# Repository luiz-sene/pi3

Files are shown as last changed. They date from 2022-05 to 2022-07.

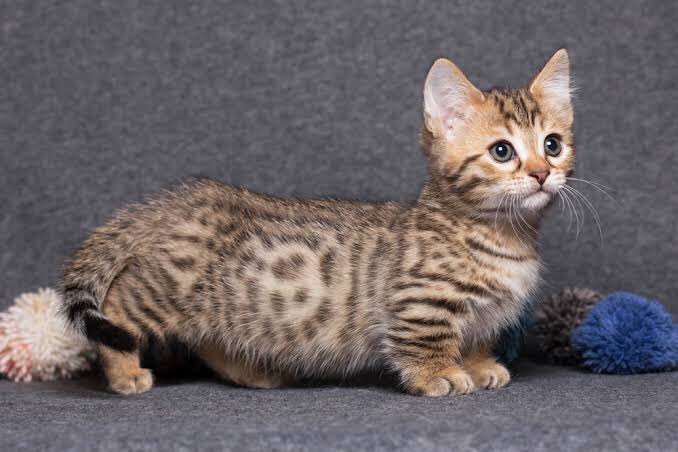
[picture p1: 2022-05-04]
Imagens/image.png

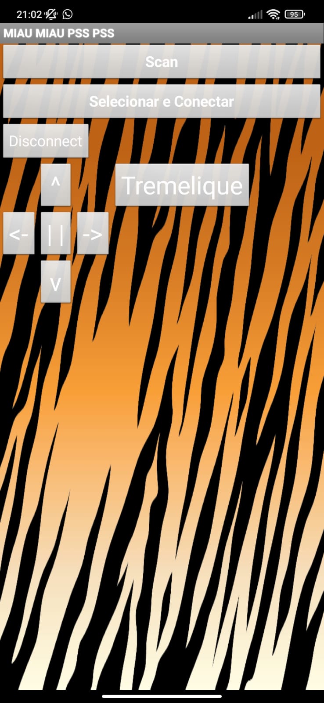
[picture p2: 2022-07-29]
Imagens/App Miau Miau.jpeg

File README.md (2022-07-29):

 # README

Este repositório possui o desenvolvimento do projeto da disciplina Projeto Integrador III realizado pelo alunos Julio Sidney Veras Pacheco e Luiz Fernando Assis Sene.

[Concepção](https://github.com/juliopacheco12/PIN22107/blob/main/CONCEPÇÃO.md)

[Design](https://github.com/juliopacheco12/PIN22107/blob/main/Design.md)

[Implementação](https://github.com/juliopacheco12/PIN22107/blob/main/Implementação.md)

[Repositório de Códigos de Programação](https://github.com/juliopacheco12/PIN22107/tree/main/Programação)

[Repositório de Projeto de PCI](https://github.com/juliopacheco12/PIN22107/tree/main/PCI)

[Repositório do App](https://github.com/juliopacheco12/PIN22107/tree/main/App)

[Repositório de Imagens](https://github.com/juliopacheco12/PIN22107/tree/main/Imagens)

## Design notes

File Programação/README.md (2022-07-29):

# Repositorio de codigos e configurações

Todos os codigos foram gerados tendo como alvo o microcontrolador ESP32. Os arquivos principais se encontram na pasta Main e estão divididos da seguinte forma:

Main - arquivo principal.

servomotor.c/.h - inicialização do motor, configuração dos parametros necessários e a função para ele seja ativado.

sensor.c/.h     - inicialização do sensor, configuração dos parametros necessários e uma função para detectar o obstaculo e ativar o motor.

pwm.c/.h        - inicialização dos pwm, configuração dos parametros necessários e funções para definir a movimentação do carrinho

bt.c/.h         - repositorio de codigos relacionados ao bluetooth. E nele tambem onde a informação enviada pelo aplicativo e recebida e então ele chama a função
                  desejada pelo usuario, como se movimentar ou ativar o motor. Na linha 377 do bt.c e possível ver quando o evento de escrita e ativado e como é
                  feita a comparação para que a função correta seja chamada.

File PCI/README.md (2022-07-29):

#PCI
Pasta com arquivos do projeto da PCI utilizada para acoplar o ESP32 ao carrinho do IFSC

## PINAGEM
|Signal|ESP Pin|
|:-:|:-:|
|Echo 0|32|
|Triger 0|33|
|Echo 1|23|
|Triger 1|22|
|Optico Direita|2|
|Optico Esquerda|15|
|PWM 1|19|
|PWM 1N|18|
|PWM 2|26|
|PWM 2N|25|
|Servo Motor|4|
|Sensor de presença|12|

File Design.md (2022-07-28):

# Design
Seguindo as necessidades apontadas na concepção do projeto, apresentaremos os componentes que serão utilizados neste projeto, bem como analisaremos as escolhas de acordo com as caracteristicas de alguns componentes do mercado.

## Componentes

|Quantidade|Componente|Custo no Mercado|Custo no Projeto|
|:-:|:-:|:-:|:-:|
|1|Microcontrolador|R$69,90|R$-|
|1|Módulo Bluetooth|Integrado ao Microcontrolador|R$-|
|1|Sensor de Obstáculo|R$49,90|R$-|
|1|Servomotor|R$59,90||
|1|Bateria 9V recarregavel|R$19,98|R$-|
|1|Haste Flexivel com bagulhinho na ponta|R$-|R$-|
|1|Módulo de carrinho Vrum Vrum|R$-|R$-|
||Total|R$199,98|R$0,00|

O custo total deste projeto foi zerado pois todos os componentes utilizados estavam disponíveis nos laboratórios do DAELN/IFSC.

## Bluetooth VS WiFi

|#|  **BLUETOOTH** | **WIFI** |
|:-|:-:|:-:|
|Protocolo de Comunicação|IEEE 802.15.1|802.11|
|Frequencia (Hz)|2,4G|2,4~5G|
|Alcance|Até 100m|Maior que 100m|
|Custo de Mercado*|R$27,90|R$24,90|
|Alimentação|Baixo Consumo|Alto Consumo|
|Vantagem|Baixo Custo|Longo Alcance|
|Desvantagem|Baixo Alcance|Alto consumo energético|

*Pesquisado em 04/05/2022 - FilipeFlop

### Escolha
O módulo de comunicação escolhido foi o bluetooth devido ao baixo consumo energético deste dispositivo; apesar do baixo alcançe, atende a necessidade deste projeto; além disso, já temos familiardade com este dispositivo devido a trabalhos anteriores.

## Microcontrolador

Possibilidades
 1. ESP32
 2. Cortex M3
 3. ATMEGA328

O microcontrolador escolhido foi o ESP32, pois é o que melhor atende as nossas necessidades. Ele já possui módulos de comunicação bluetooth e wifi integrados, possui 4Mb de memória flash, que será utilizada para armazenamento dos dados coletados da aplicação, é um componnente que possui uma boa eficiencia no consumo energético, com diversos modos sleeps. Ele possui uma quantidade de pinos suficiente para este projeto, com 18 canais ADC, 34 portas GPIO, PWM e outras.

Além disso, ele está disponível junto ao professor Charles, que trabalhará com este microcontrolador na disciplina de Microcontroladores 2.

## Framework

Foi utilizado o framework ESP-IDF, que é o framework oficial da Espressif para o desenvolvimento de aplicações parar toda a família ESP32.

## ServoMotor

Já tivemos experiência com o Servomotor Tower Pro SG90. Este servomotor pode rotacionar em aproximadamente 180º, 90º para cada lado. Possui cerca de 9g e 3 pinos analógicos: VCC, GND e comando. Ele opera em um torque de 8kgfcm, velocidade de 60º/0.1s e tensão de operação de 3V a 7,2V. Por fim, ele é um dos mais baratos do mercado. Infelizmente, este componente é extremamente frágil e não conseguiremos utilizá-lo de forma satisfatória. 

Outro servomotor disponível nos laboratórios foi o MG995. O Servo TowerPro MG995 possui ótima qualidade e alto torque, todas as suas engrenagens são metálicas, possui faixa de rotação de 180 graus, a tensão de operação é de 4,8V a 7,2V (facilmente atingida por meio das baterias do carrinho). Por fim, sua escolha se deu principalmente por sua robustez, que atingia as necessidades do projeto.

## Sensor de proximidade

O sensor de obstáculo é um circuito composto por um emissor e um receptor IR, mais o CI comparador LM393, que facilita sua conexão com Arduino, PIC ou Raspberry Pi, visto que sua tensão é de 3,3-5V.

Seu funcionamento é simples: quando algum obstáculo é colocado em frente ao sensor, o sinal infravermelho é refletido para o receptor. Quando isso acontece, o pino de saída OUT é colocado em nível baixo (0), e o led verde do módulo é aceso, indicando que algum obstáculo foi detectado.

O alcance do sensor é de 3 à 80 cm, que pode ser ajustado por meio do potenciômetro na placa. O sensor de obstáculo é um componente que atende as nossas necessidades.

### Escolha

Sensor de Obstaculo Infravermelho - E18-D80NK

## Bateria

2 Baterias de litio em série que já estão inseridas no prototipo do carrinho disponibilizado pelo DAELN 3,7V. Para alimentar o esp32 foi utilizado um Power Bank independente de 5V.

## Regulador de tensão chaveado

Regulador de Tensão LM2596 Conversor DC-DC Step Down ou similar

## Interface para Usuário

Existem alguns softwares no mercado para implementar uma interface de controle para o usuário. Neste projeto, pensamos em 2 opções: implementar uma interface para o usuário no Qt Creator, orientando toda a programação deste projeto a objetos; ou utilizar o MIT App Inventor para implementar um aplicativo para smartphone.

O Qt Creator é um ambiente de desenvolvimento integrado (IDE) multiplataforma criado para a máxima experiência do desenvolvedor. O Qt Creator é executado nos sistemas operacionais de desktop Windows, Linux e macOS e permite que os desenvolvedores criem software em plataformas desktop, móveis e incorporadas.

O MIT App Inventor é um ambiente de programação visual intuitivo que permite que todos criem aplicativos totalmente funcionais para telefones Android, iPhones e tablets Android/iOS. Essa ferramenta é baseada em blocos, facilitando a criação de aplicativos complexos e de alto impacto em um tempo significativamente menor do que os ambientes de programação tradicionais.

No caso do Qt Creator, pudemos ter o auxilio e orientação do Profº Hugo Marcondes, na disciplina de Programação Orientada a Objetos. No entanto, nesta disciplina utilizamos apenas o framework do Arduino para implementar nossos objetivos. Como este framework era dispensável para a disciplina de Projeto Integrador III, implementamos também uma interface final no MIT App Inventor.

## Placa de Circuito Impresso

Foi implementado também uma placa de circuito impresso para acoplar com facilidade o microcontrolador escolhido com o cabo flet do carrinho. Para isto, foi utilizado o software KiCad, que é um programa computacional de código aberto para projeto eletrônico assistido por computador, com o objetivo de facilitar a concepção de layouts e suas conversões para placas de circuito impresso. Além dele, foi utilizado as instalações do IFSC para a confecção da placa.

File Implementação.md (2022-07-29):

# IMPLEMENTAÇÃO
Nesta etapa do projeto colocaremos em prática o que foi abordado e definido pelas etapas anteriores. De forma a atingir os objetivos estipulados, podemos definir duas diferentes frentes de trabalho. Programação e Montagem do equipamento.

## Programação

O primeiro passo foi realizar testes com os componentes individualmente de forma a verificar e compreender seu funcionamento. Ao longo deste processo pode-se notar que muito do que era feito ali poderia e foi integrado ao código final. Para tal, foi instalado o ESP-IDF, o qual foi utilizado junto ao VS-CODE para implementar todas as funcionalidades desejadas. Este ambiente de desenvolvimento suporta as linguagens C e C++, além de já possuir alguns exemplos que nos guiaram. Apesar destes exemplos, é importante destacar a grande dificuldade de encontrar bibliografia suficiente para o entendimento pleno da utilização deste framework.

Cada componente foi testado separadamente através de rotinas simples, após isso métodos de interação entre eles foram gerados, resultando em um código funcional que atende as exigências do projeto. Inicialmente, optamos por realizar a comunicação via bluetooth, visto que a partir deste ponto poderíamos prosseguir com a implementação de todo o restante das nossas funcionalidades de forma mais fluída. Para os futuros projetos que desejem seguir com esta implementação, é importante mencionar que foi justamente aqui que encontramos a nossa maior dificuldade durante todo o processo: tornar o código exemplo do Bluetooth em modo de economia de energia funcional às nossas necessidades. Após muito estudo, conseguimos manipular os dados enviados ao esp32 de forma que para cada dado recebido uma ação fosse desencadeada, uma mensagem serial de confirmação também é exibida no serial monitor. Embora para este projeto não tenha sido utilizado, o ato do esp32 enviar dados via bluetooth e não apenas receber, também está funcional. Após a comunicação ser implementada conforme desejávamos, iniciamos a criação do Aplicativo para Smartphone, a qual seria a nossa interface de controle do usuário. O objetivo desta interface era escanear a procura do dispositvo bluetooth desejado, esp32, e uma vez conectado que ele pudesse enviar dados de forma que controlasse o movimento do carrinho e o motor da haste. Para que esta comunicação fosse realizada ambos os dispositvos, a interface e o esp32, precisavam ter o mesmo service uuid, um numero de 128 bits utilizado para identificar informações, uma vez que ele não era disponibilizado na documentação do ESP-IDF foi utilizado um aplicativo disponivel na playstore para se conectar com o microcontrolador e uma vez que ele enviava dados era possivel analisar o log gerado por esse aplicativo para identificar esse numero e implementa-lo na interface. Para o caso dos motores do carrinho, foi importante entender a documentação disposta no GitHub do LPAE, encontrada [clicando neste link](https://github.com/xtarke/automated_buggy). Implementamos os 4 PWMs necessários para o correto funcinonamento dos motores de acordo com as nossas necessidades. Ao receber os comandos via comunicação bluetooth, o acionamento ocorria de forma satisfatória. Lembrando que o acionamento do carrinho era desejado APENAS por meio da interface do usuário. Por fim, implementamos o servo motor e o sensor de obstáculo. Para o servo motor, implementamos uma rotação de 90º para ambos os lados, fazendo com que este gire o que chamamos de "tremelique". Neste protótipo, implementamos apenas uma volta de 90º no sentido horário e outro no sentido anti-horário, de forma a ser uma validação de conceito. O sensor de obstáculo foi implementado enviando um sinal ao ESP32, o qual ativa o servo motor sempre que o sensor detecta um obstáculo próximo. Portanto, conforme desejado inicialmente, o acionamento do tremelique ocorre por 2 métodos: Controle do usuário por meio do aplicativo, ou aproximação do felino sendo detectada pelo sensor de obstáculo. Após todos os testes individuais, pudemos realizar o código final com todas as aplicações requeridas por este projeto juntas e funcionais. O código podeser acessado por meio do link abaixo. Reforço que ara este código ser compilado, é necessário o a correta instalação do ESP-IDF, bem como a criação de novo projeto.

Aplicativo

### Código esp32
[Clique aqui para ver o código deste projeto](https://github.com/juliopacheco12/PIN22107/tree/main/Programação).

### App
[Clique aqui para ver o código do App](https://github.com/juliopacheco12/PIN22107/tree/main/App)

## Montagem
Assim como na parta da programação, inicialmente realizamos todos os testes individuais, de forma a entender o funcionamento dos componentes utilizados. Caso este projeto seja continuado, é de extrema importância o entendimento do funcionamento do carrinho por meio da documentação disponibilizada pelos laboratórios responsáveis por todos os carrinhos disponibilizados pelo IFSC. O teste dos PWMs ocorreram primeiramente com o auxilio de um osciloscópio, onde pudemos verificar o correto funcionamento. Testamos também este acionamento com o auxilio de 4 leds, onde pudemos verificar o correto acionamento de todas as direções desejadas e acionadas pelo controle do usuário.

Antes de conectar todos os componentes ao carrinho, decidimos testar o acionamento do servo motor e do sensor de obstáculo juntamente aos leds na brotoboard, verificando e corrigindo algumas inconsistências do código. Logo após todos os testes, acoplamos todos os componentes ao carrinho. Nesta etapa, realizamos a calibragem dos PWMs, conseguindo acionar corretamente o giro de todas as rodas, de forma a fazê-lo andar em todas as direções conforme desejado e acionado pelo controle do usuário.

Após confirmarmos o funcionamento de todos os componentes integrados, desejamos corrigir um detalhe que poderia nos causar problemas: a utilização de cabos. Para isto, realizamos a confecção de uma placa de circuito impresso, onde pudemos acoplar o ESP32 de forma a realizar todas as conexões com a mínima utilização de cabos jumper necessária. Acoplamos também o conector para o cabo flat do carrinho, o qual se conectá a todas as funcionalidades que o carrinho possui. Infelizmente, passamos por problemas nesta etapa que nos fez abortar a utilização desta PCI na apresentação final do projeto. Os problemas já foram corrigidos no layout da placa projetada, o qual pode ser encontrado [clicando neste link](https://github.com/juliopacheco12/PIN22107/tree/main/PCI), porém não houve tempo hábil para a nova impressão.

Felizmente, apesar de não ter a placa para acoplar os componentes, realizamos a montagem de todos os componentes "a bordo" do carrinho, e o funcionamento de toda a estrutura pode ser confirmado em sala de aula.

Carrinho

Por fim, devido ao encurtamento do semestre 2022/1, o qual teve menos semanas que um semestre comum no IFSC, visto a necessidade de tornar o calendário acadêmico normal novamente pós pandemia, alguns pontos desejados não puderam ser implementados.
1. Nova placa de circuito impresso;
2. Impressão 3D da haste flexível;
3. Impressão 3D de estrutura de suporte para os componetes para acoplar ao carrinho.

Era de desejo nosso realizar estes três pontos, mas infelizmente não foi possível. Como citado, solucionamos a falta destes pontos da seguinte forma:
1. Estrutura de cabos jumper para conexão entre componentes, validando o caso;
2. Apenas realizando validação do funcionamento servo motor, visto que esta estrutura seria acoplada às hastes giratórias do servo e serviria apenas para "embelezar" o projeto;
3. Acoplar componentes diretamente na estrutura pré existente do carrinho.

## Sugestões para trabalhos futuros
No caso de seguimento deste projeto por algum colega, segue algumas sugestões que podem ser realizadas para aprimorar o projeto:
1. Sanar pontos não implementados citados no tópico anterior;
2. Armazenar dados de utilização;
3. Expor ao usuário dados de utilização do brinquedo;

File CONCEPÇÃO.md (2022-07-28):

# CONCEPÇÃO
  
Este projeto tem como objetivo manufaturar um protótipo de brinquedo para felinos que seja acionado automaticamente por proximidade e pelo controle do usuário, tudo isso utilizando o framework ESP-IDF. Este framework não é tão popular quanto outros, portanto surge como objetivo também desbravar suas bibliotecas e seu metodo de implementação, abrindo caminho para que mais pessoas possam compreender como utiliza-lo, pois se tratam de codigos complexos.

O brinquedo consiste em uma base móvel com 4 rodas que se movimente pelo controle do usuário, além de uma haste flexível na parte superior, a qual será ativada pela proximidade do gato. Ao ser ativada, um motor é acionado, girando a haste por um tempo determinado. Esta haste possui na ponta um chamariz para o gato, como penas ou algo similar de forma a chamar a atenção do bichano. Todo o sistema será controlado por um microcontrolador que se comunicará com um aplicativo para smartphone, permitindo a ativação e desativação do dispositivo e o controle do movimento da base móvel.

## REQUISITO

1. Movimentação da base controlada por aplicativo para smartphone
2. Acionamento da haste flexível por um sensor de proximidade
3. Comunicação via Bluetooth

## CONCORRENTE

Foi encontrado apenas um concorrente, que possui comunicação e controle apenas por controle remoto, alimentado por pilhas. Não há muita especificação encontrada na internet, mas as diferenças citadas acima do nosso projeto já foram encontradas. 

## Publico Alvo

Publico Alvo

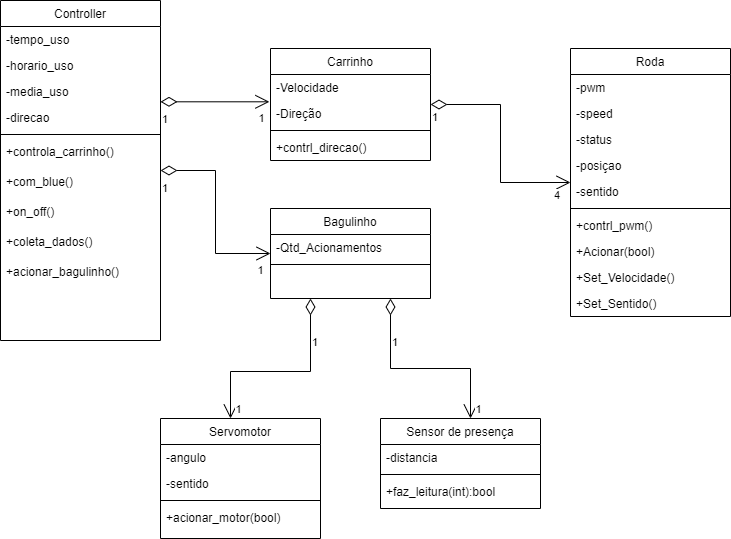
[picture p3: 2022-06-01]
Imagens/Diagrama de classes.drawio - lastone.png

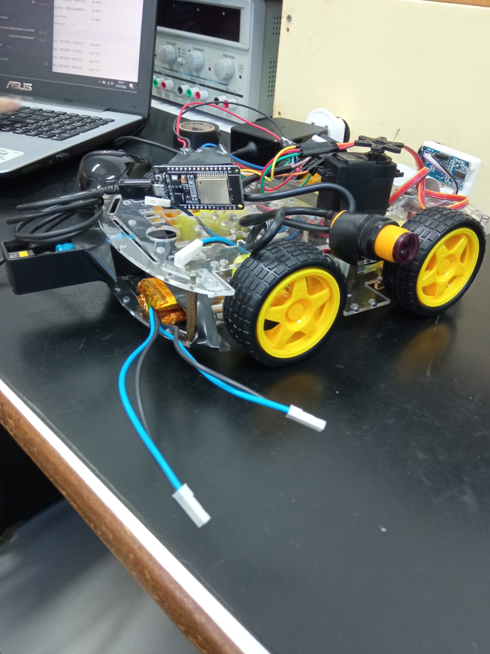
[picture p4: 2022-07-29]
Imagens/Carrinho Vrum Vrum.jpeg

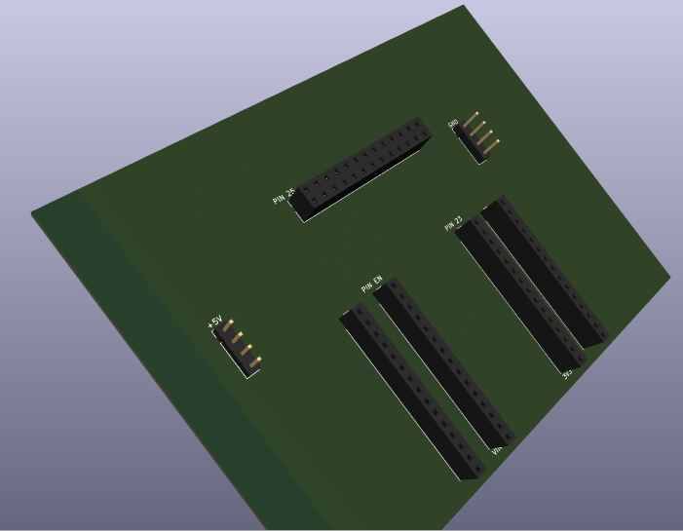
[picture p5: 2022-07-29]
PCI/pcb3d.png

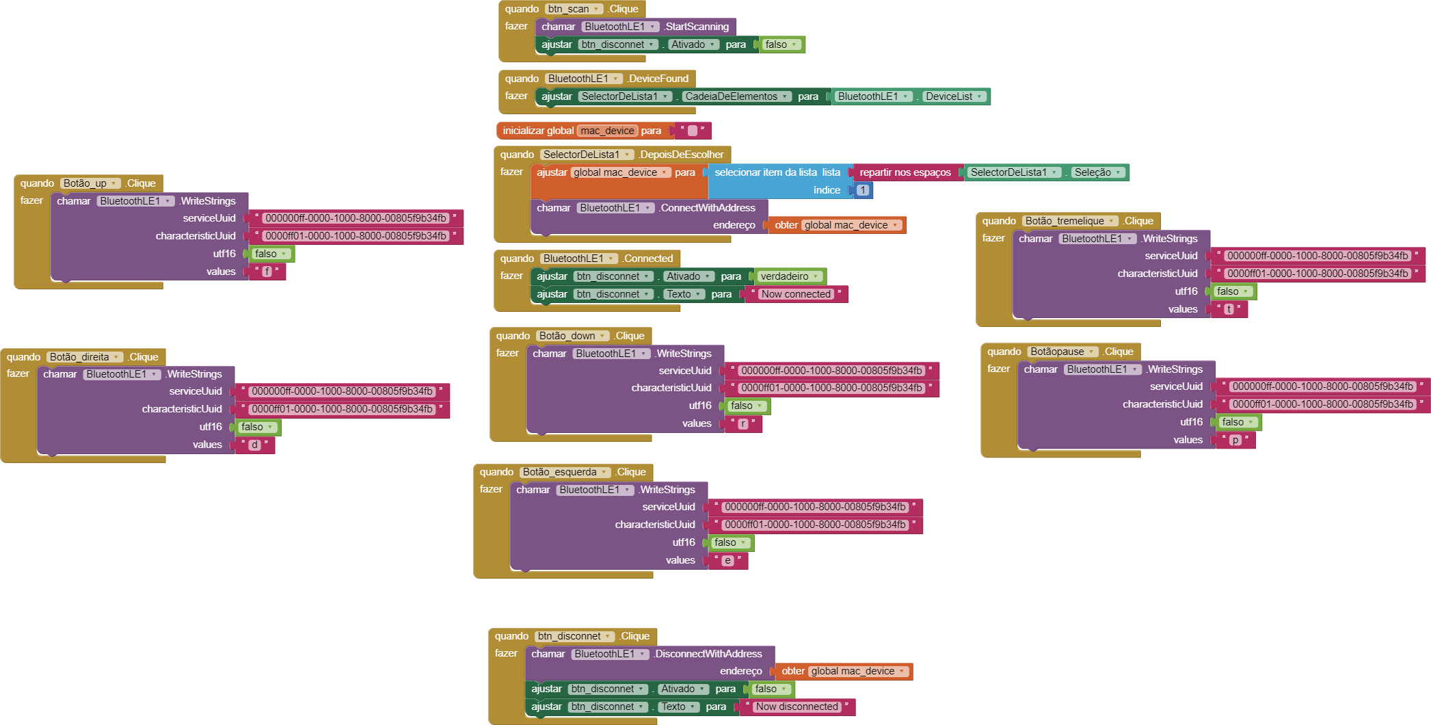
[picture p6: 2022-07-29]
App/blocks.png

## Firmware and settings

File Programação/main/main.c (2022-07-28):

#include "pwm.h"
#include "sensor.h"
#include "servomotor.h"
#include "bt.h"
#include "freertos/FreeRTOS.h"
#include "freertos/task.h"

void app_main(void)
{
   
/*inicia as configurações do ledc*/
   ledc_init_DF();
   ledc_init_EF();


   ledc_init_DF_r();
   ledc_init_EF_r();

   /*inicializa sensor*/
   init_sensor();

   /*inicializa servo motor*/
   init_servomotor();

/*função que chama as diversas funções do bt*/   
   rotina_bt();
   while(1){
      verifica_sensor();
      vTaskDelay(pdMS_TO_TICKS(1000));
   }

}

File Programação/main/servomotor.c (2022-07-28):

#include "freertos/FreeRTOS.h"
#include "freertos/task.h"
#include "esp_log.h"
#include "driver/mcpwm.h"
#include "servomotor.h"

#define SERVO_MIN_PULSEWIDTH_US (1000) // Minimum pulse width in microsecond
#define SERVO_MAX_PULSEWIDTH_US (2000) // Maximum pulse width in microsecond
#define SERVO_MAX_DEGREE        (90)   // Maximum angle in degree upto which servo can rotate

#define SERVO_PULSE_GPIO        (4)   // GPIO connects to the PWM signal line

inline uint32_t example_convert_servo_angle_to_duty_us(int angle)
{
    return (angle + SERVO_MAX_DEGREE) * (SERVO_MAX_PULSEWIDTH_US - SERVO_MIN_PULSEWIDTH_US) / (2 * SERVO_MAX_DEGREE) + SERVO_MIN_PULSEWIDTH_US;
}

void init_servomotor(void){
    
    mcpwm_gpio_init(MCPWM_UNIT_0, MCPWM0A, SERVO_PULSE_GPIO); // To drive a RC servo, one MCPWM generator is enough

    mcpwm_config_t pwm_config = {
        .frequency = 50, // frequency = 50Hz, i.e. for every servo motor time period should be 20ms
        .cmpr_a = 0,     // duty cycle of PWMxA = 0
        .counter_mode = MCPWM_UP_COUNTER,
        .duty_mode = MCPWM_DUTY_MODE_0,
    };
    mcpwm_init(MCPWM_UNIT_0, MCPWM_TIMER_0, &pwm_config);
}
void tremelica(void){
        for (int angle = -SERVO_MAX_DEGREE; angle < SERVO_MAX_DEGREE; angle++) {
        ESP_ERROR_CHECK(mcpwm_set_duty_in_us(MCPWM_UNIT_0, MCPWM_TIMER_0, MCPWM_OPR_A, example_convert_servo_angle_to_duty_us(angle)));
        vTaskDelay(pdMS_TO_TICKS(15)); //Add delay, since it takes time for servo to rotate, generally 100ms/60degree rotation under 5V power supply
        }
        for (int angle = SERVO_MAX_DEGREE; angle > -SERVO_MAX_DEGREE; angle--) {
        ESP_ERROR_CHECK(mcpwm_set_duty_in_us(MCPWM_UNIT_0, MCPWM_TIMER_0, MCPWM_OPR_A, example_convert_servo_angle_to_duty_us(angle)));
        vTaskDelay(pdMS_TO_TICKS(15)); //Add delay, since it takes time for servo to rotate, generally 100ms/60degree rotation under 5V power supply
        }
}

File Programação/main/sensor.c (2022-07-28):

#include <stdio.h>
#include "freertos/FreeRTOS.h"
#include "freertos/task.h"
#include "driver/gpio.h"
#include "sdkconfig.h"
#include "sensor.h"
#include "servomotor.h"

#define SNR 12
#define ON 1
#define OFF 0

static bool last_state_snr = 0; // Armazena o último estado do botão
    
/*incializa o sensor como entrada*/
void init_sensor(void){

    gpio_pad_select_gpio(SNR);
    gpio_set_direction(SNR, GPIO_MODE_INPUT);
}
/*verifica o sinal do sensor*/
void verifica_sensor(void){

    bool state_snr = gpio_get_level(SNR);

    if (!state_snr && !last_state_snr)
    {
        last_state_snr = true;
        tremelica();
    }
    else if(state_snr && last_state_snr)
    {
        last_state_snr = false;
    }
    return;
}
